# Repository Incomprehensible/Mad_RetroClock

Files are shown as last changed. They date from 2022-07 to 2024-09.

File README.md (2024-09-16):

# Retro style desk clock

Powered via 5V USB-C interface. Provides a 2S Li-Ion battery pack for autonomous operation.\
Made with 4 IN-12A Nixie Tubes denoting hours & minutes, and smaller INS-1 tubes as the dots.\
Enabled with Wi-Fi connectivity for automatic time synchronization using the Network Time Protocol (NTP).\
Functions as a simple clock and an alarm clock. User interface for the alarm setting is implemented with 2 Set/Unset buttons and rotary encoder.\
There's an MP3-player onboard any melody can be programmed and set as an alarm call.





## Gallery
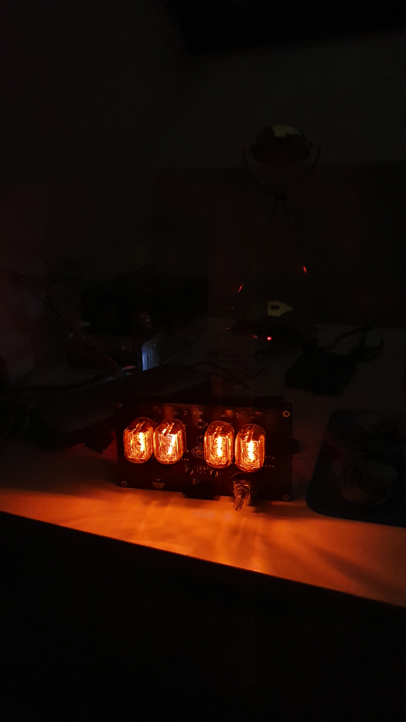
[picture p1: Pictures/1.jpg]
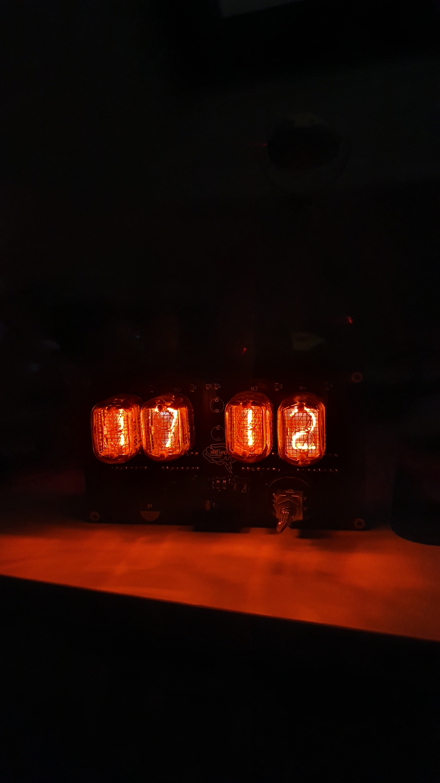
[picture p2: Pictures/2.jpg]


<details><summary>More photos</summary>
<p>

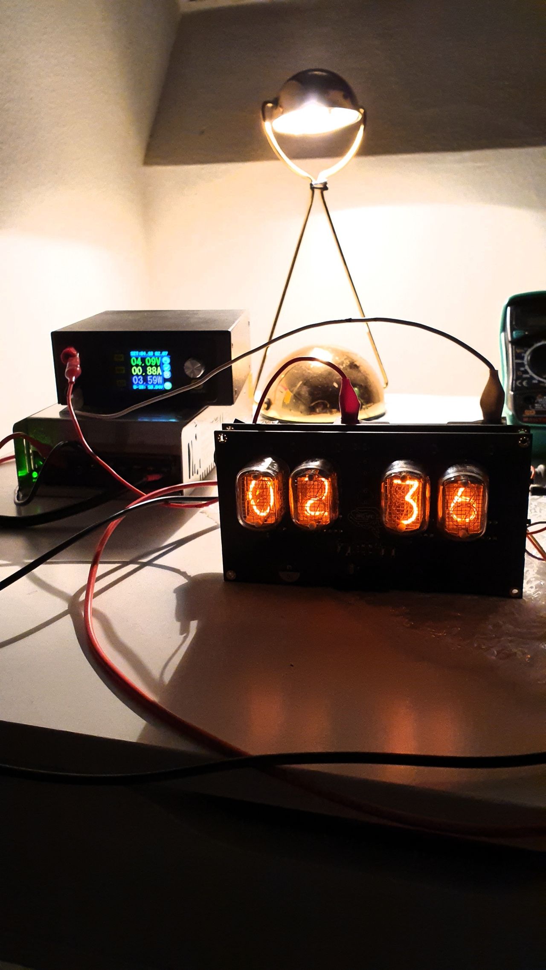
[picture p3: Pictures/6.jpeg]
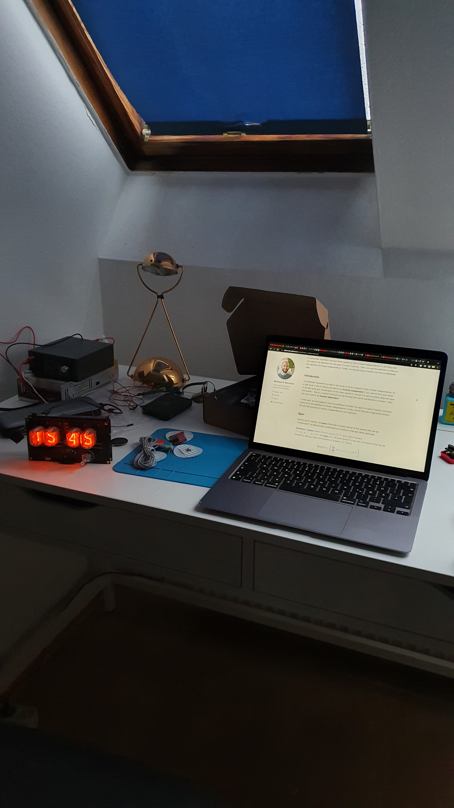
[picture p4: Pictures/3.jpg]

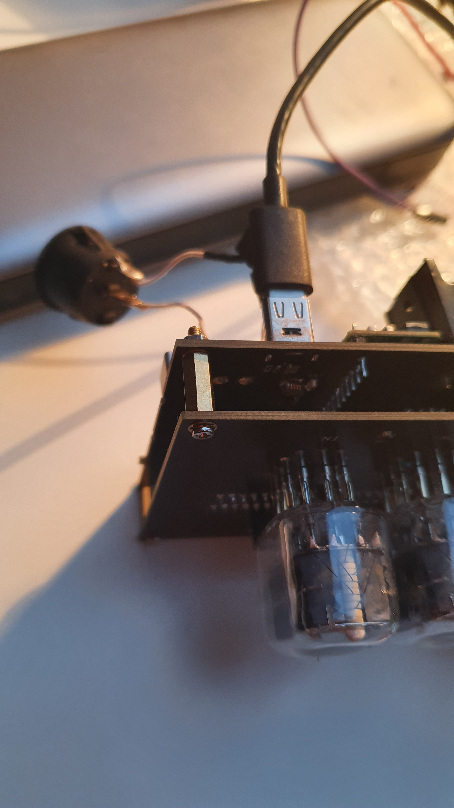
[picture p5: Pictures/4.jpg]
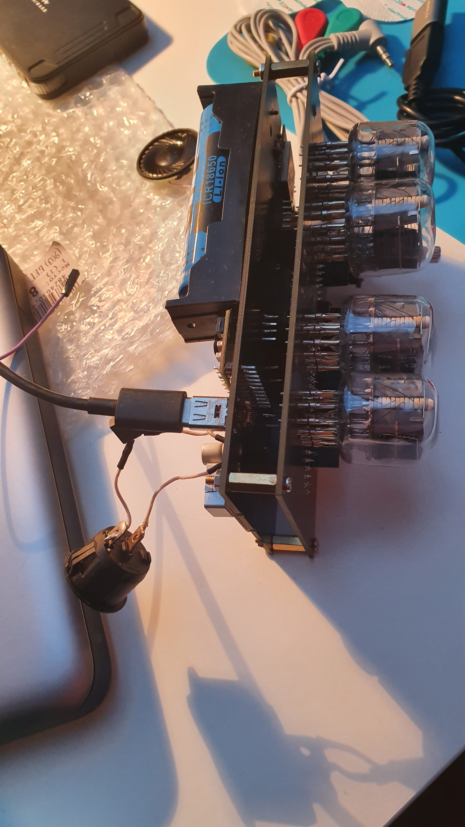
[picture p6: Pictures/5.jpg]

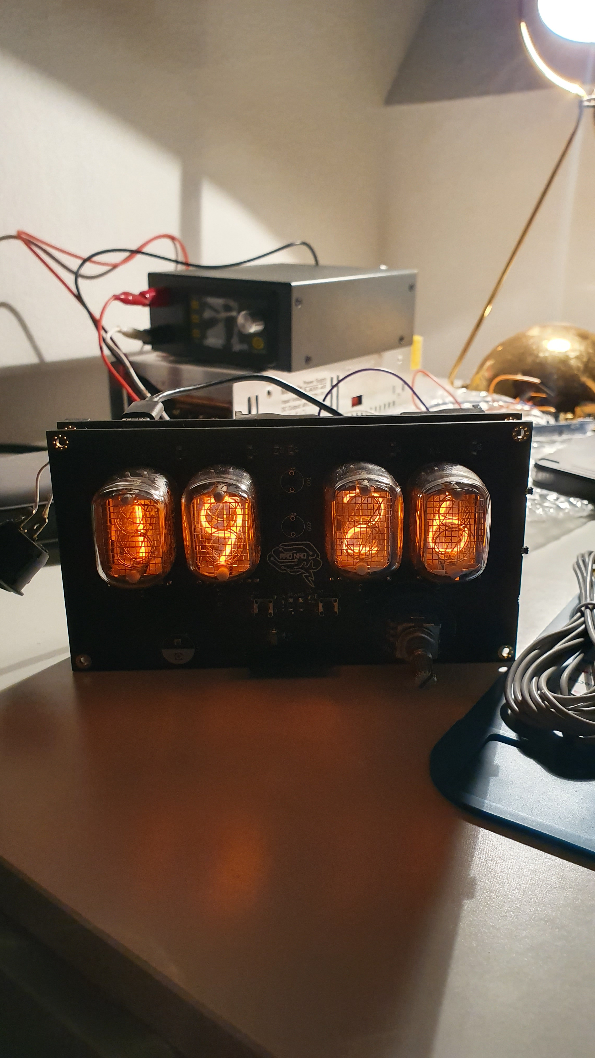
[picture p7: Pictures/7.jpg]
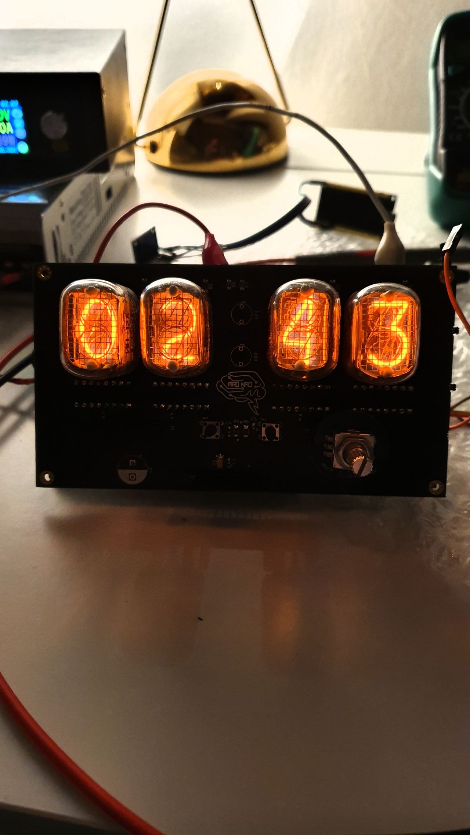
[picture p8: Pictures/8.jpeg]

</p>
</details>

## Further steps
* Enclosure design
* Add remote app control / IOT host node connectivity
* Better power design to get rid of inrush current issue preventing the device to start up sometimes without USB power attached

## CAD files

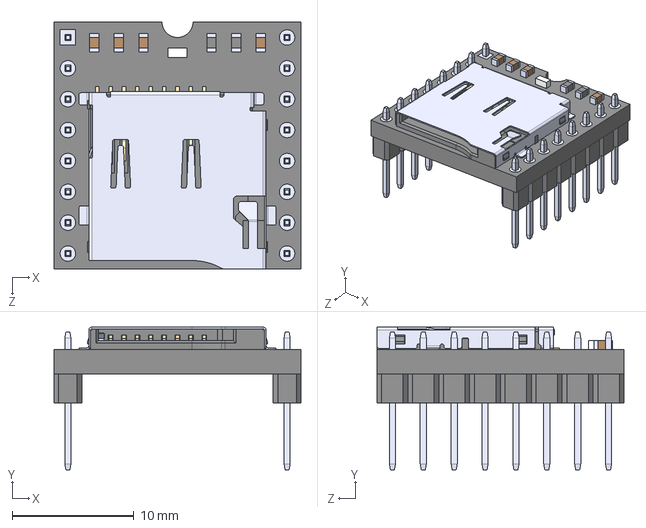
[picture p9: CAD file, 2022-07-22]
3D/DFR0299.step
20.3 x 11.8 x 20.3 mm

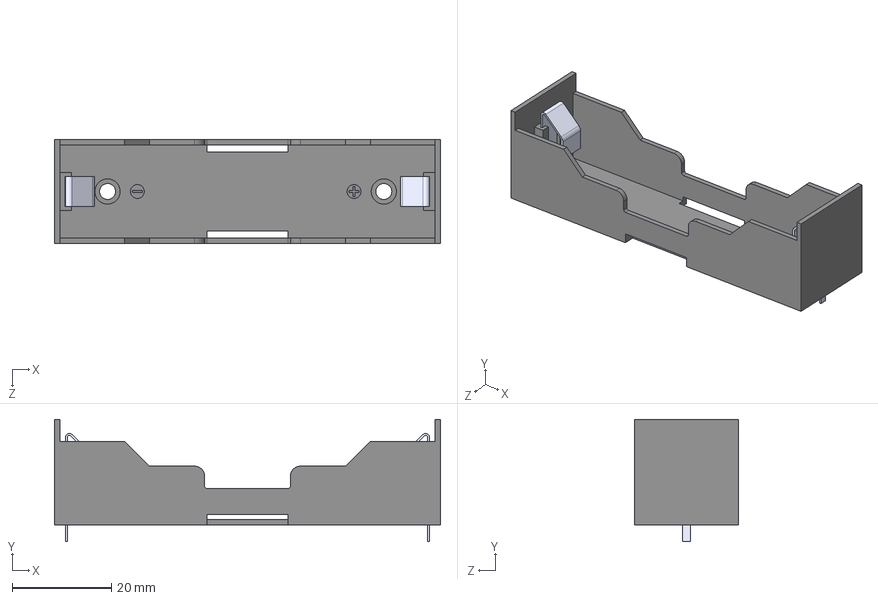
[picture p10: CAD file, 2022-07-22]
3D/BH-18650-PC.step
77.7 x 24.6 x 20.9 mm

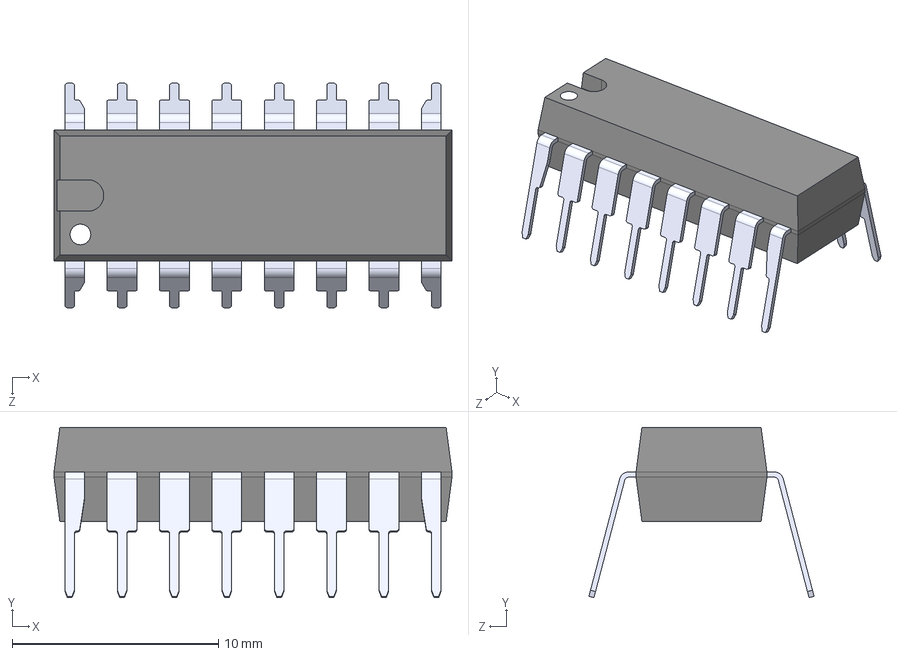
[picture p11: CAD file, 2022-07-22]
3D/SN74HC595N.step
19.3 x 8.25 x 10.9 mm

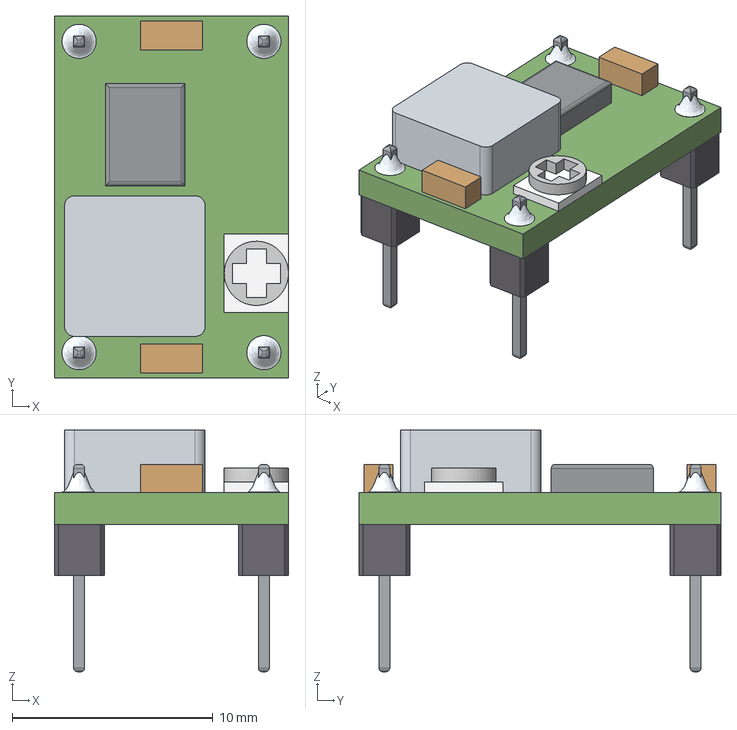
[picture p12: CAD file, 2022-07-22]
3D/dsn-mini-360.step
11.7 x 18.0 x 12.0 mm

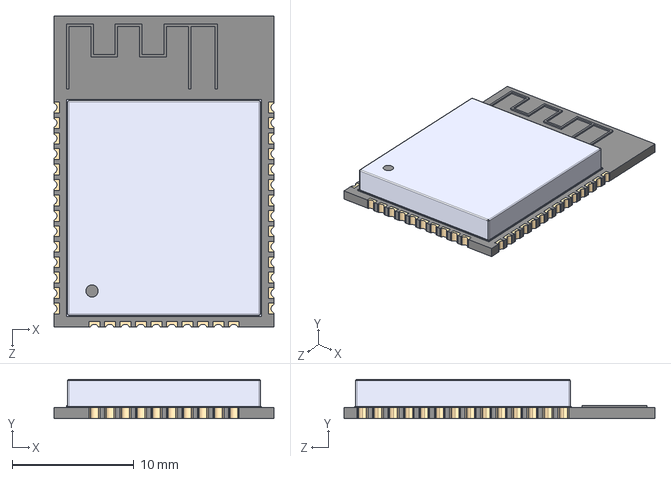
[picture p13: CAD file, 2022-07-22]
3D/ESP32-WROOM-32.step
18.0 x 3.20 x 25.5 mm

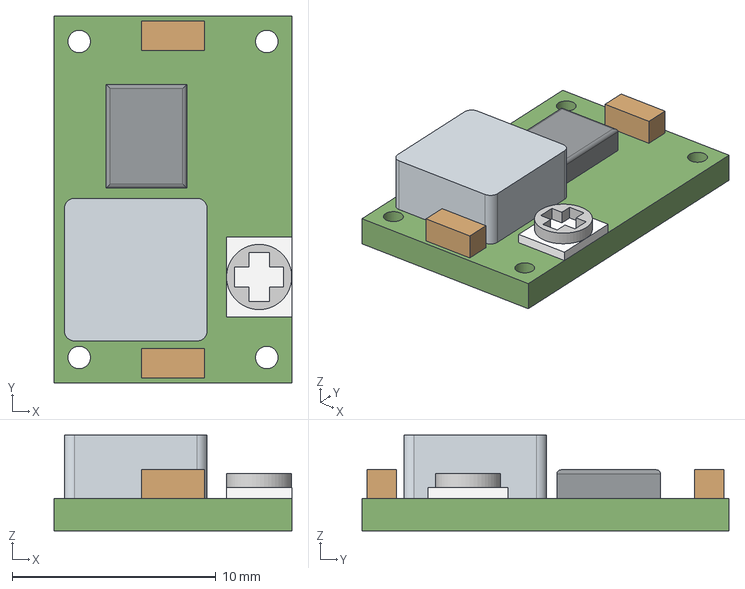
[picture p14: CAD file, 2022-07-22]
3D/dsn-mini-360-no-pins.step
11.7 x 18.0 x 4.70 mm

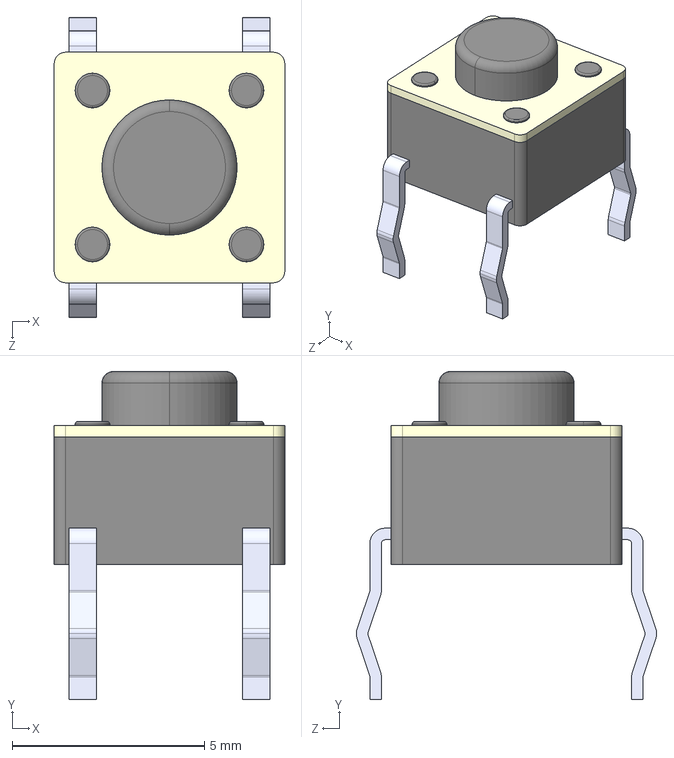
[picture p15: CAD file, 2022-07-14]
3D/KLS7-TS6601-13.0-180.step
5.99 x 8.52 x 7.80 mm

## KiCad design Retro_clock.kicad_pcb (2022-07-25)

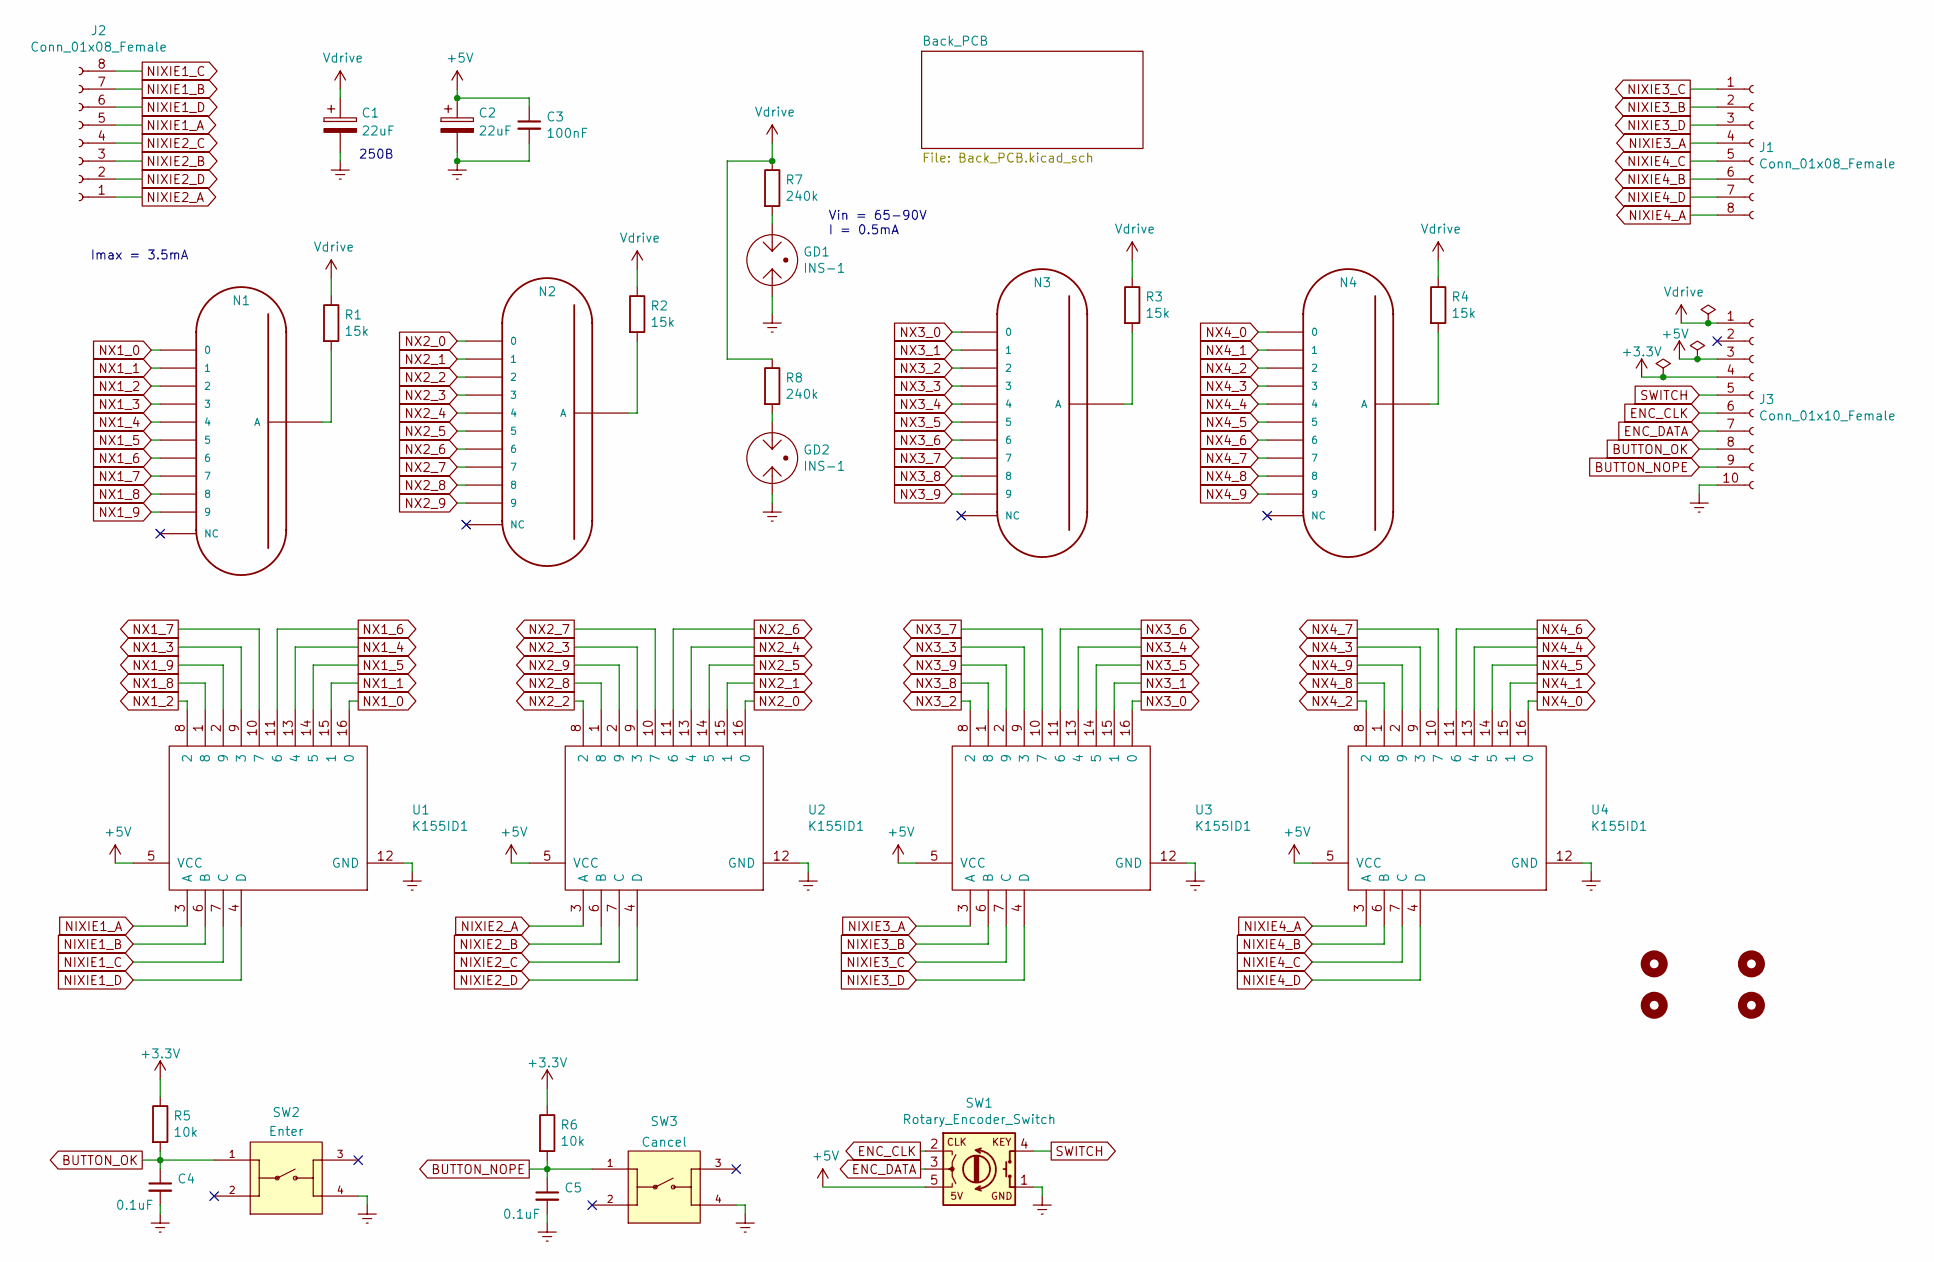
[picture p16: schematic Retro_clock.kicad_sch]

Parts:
C1: 22uF; CP_Radial_D10.0mm_P5.00mm
C2: 22uF; CP_EIA-3216-10_Kemet-I_Pad1.58x1.35mm_HandSolder
C3: 100nF; C_0603_1608Metric_Pad1.08x0.95mm_HandSolder
C4, C5: 0.1uF; C_0603_1608Metric_Pad1.08x0.95mm_HandSolder
GD1, GD2: INS-1
H1, H2, H3, H4: MountingHole; MountingHole_2.5mm_Pad_Via
J1, J2: Conn_01x08_Female; PinSocket_1x08_P2.54mm_Vertical
J3: Conn_01x10_Female; PinSocket_1x10_P2.54mm_Vertical
N1, N2, N3, N4: IN-12A
R1, R2, R3, R4: 15k; R_1206_3216Metric_Pad1.30x1.75mm_HandSolder
R5, R6: 10k; R_1206_3216Metric_Pad1.30x1.75mm_HandSolder
R7, R8: 240k; R_0805_2012Metric_Pad1.20x1.40mm_HandSolder
SW1: Rotary_Encoder_Switch; Encoder
SW2: Enter; KLS7-TS6601-13.0-180
SW3: Cancel; KLS7-TS6601-13.0-180
U1, U2, U3, U4: K155ID1; DIP-16_W7.62mm

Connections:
+3.3V: J3.4, R5.1, R6.1
+5V: C2.1, C3.1, J3.3, SW1.5 (5V), U1.5 (VCC), U2.5 (VCC), U3.5 (VCC), U4.5 (VCC)
BUTTON_NOPE: C5.1, J3.9, R6.2, SW3.1
BUTTON_OK: C4.1, J3.8, R5.2, SW2.1
ENC_CLK: J3.6, SW1.2 (CLK)
ENC_DATA: J3.7, SW1.3 (DATA)
Earth: C1.2, C2.2, C3.2, C4.2, C5.2, GD1.2, GD2.2, J3.10, SW1.1 (GND), SW2.4, SW3.4, U1.12 (GND), U2.12 (GND), U3.12 (GND), U4.12 (GND)
NIXIE1_A: J2.5, U1.3 (A)
NIXIE1_B: J2.7, U1.6 (B)
NIXIE1_C: J2.8, U1.7 (C)
NIXIE1_D: J2.6, U1.4 (D)
NIXIE2_A: J2.1, U2.3 (A)
NIXIE2_B: J2.3, U2.6 (B)
NIXIE2_C: J2.4, U2.7 (C)
NIXIE2_D: J2.2, U2.4 (D)
NIXIE3_A: J1.4, U3.3 (A)
NIXIE3_B: J1.2, U3.6 (B)
NIXIE3_C: J1.1, U3.7 (C)
NIXIE3_D: J1.3, U3.4 (D)
NIXIE4_A: J1.8, U4.3 (A)
NIXIE4_B: J1.6, U4.6 (B)
NIXIE4_C: J1.5, U4.7 (C)
NIXIE4_D: J1.7, U4.4 (D)
NX1_0: N1.2 (0), U1.16 (0)
NX1_1: N1.11 (1), U1.15 (1)
NX1_2: N1.10 (2), U1.8 (2)
NX1_3: N1.9 (3), U1.9 (3)
NX1_4: N1.8 (4), U1.13 (4)
NX1_5: N1.7 (5), U1.14 (5)
NX1_6: N1.6, U1.11 (6)
NX1_7: N1.5 (7), U1.10 (7)
NX1_8: N1.4 (8), U1.1 (8)
NX1_9: N1.3 (9), U1.2 (9)
NX2_0: N2.2 (0), U2.16 (0)
NX2_1: N2.11 (1), U2.15 (1)
NX2_2: N2.10 (2), U2.8 (2)
NX2_3: N2.9 (3), U2.9 (3)
NX2_4: N2.8 (4), U2.13 (4)
NX2_5: N2.7 (5), U2.14 (5)
NX2_6: N2.6, U2.11 (6)
NX2_7: N2.5 (7), U2.10 (7)
NX2_8: N2.4 (8), U2.1 (8)
NX2_9: N2.3 (9), U2.2 (9)
NX3_0: N3.2 (0), U3.16 (0)
NX3_1: N3.11 (1), U3.15 (1)
NX3_2: N3.10 (2), U3.8 (2)
NX3_3: N3.9 (3), U3.9 (3)
NX3_4: N3.8 (4), U3.13 (4)
NX3_5: N3.7 (5), U3.14 (5)
NX3_6: N3.6, U3.11 (6)
NX3_7: N3.5 (7), U3.10 (7)
NX3_8: N3.4 (8), U3.1 (8)
NX3_9: N3.3 (9), U3.2 (9)
NX4_0: N4.2 (0), U4.16 (0)
NX4_1: N4.11 (1), U4.15 (1)
NX4_2: N4.10 (2), U4.8 (2)
NX4_3: N4.9 (3), U4.9 (3)
NX4_4: N4.8 (4), U4.13 (4)
NX4_5: N4.7 (5), U4.14 (5)
NX4_6: N4.6, U4.11 (6)
NX4_7: N4.5 (7), U4.10 (7)
NX4_8: N4.4 (8), U4.1 (8)
NX4_9: N4.3 (9), U4.2 (9)
unnamed: GD1.1, R7.2
unnamed: GD2.1, R8.2
unnamed: N1.1 (A), R1.2
unnamed: N2.1 (A), R2.2
unnamed: N3.1 (A), R3.2
unnamed: N4.1 (A), R4.2
SWITCH: J3.5, SW1.4 (KEY)
Vdrive: C1.1, J3.1, R1.1, R2.1, R3.1, R4.1, R7.1, R8.1

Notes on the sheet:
Imax = 3.5mA
Vin = 65-90V I = 0.5mA
250В

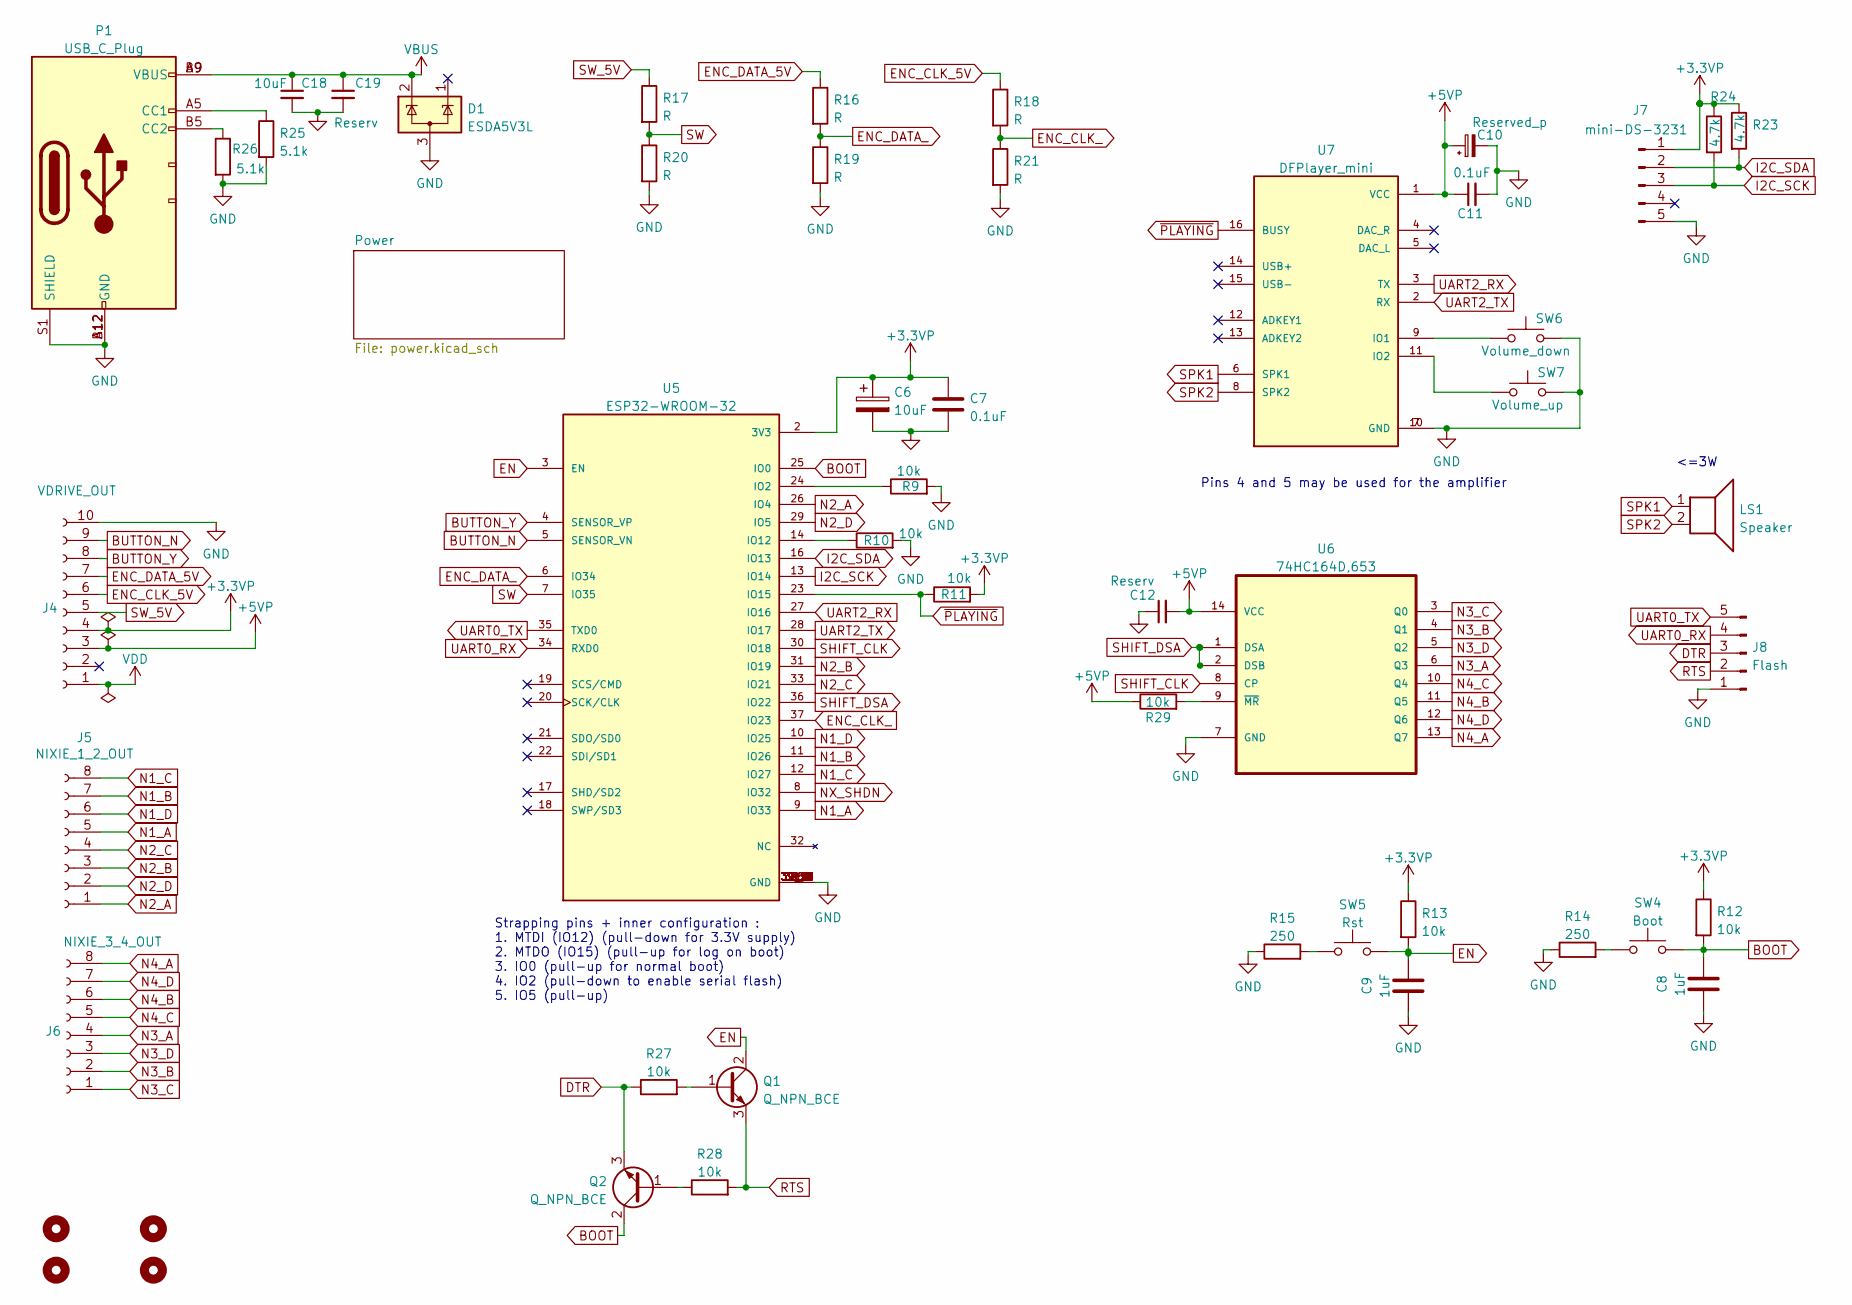
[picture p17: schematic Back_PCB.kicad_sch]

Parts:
C6, C18: 10uF; C_0603_1608Metric_Pad1.08x0.95mm_HandSolder
C7, C11: 0.1uF; C_0603_1608Metric_Pad1.08x0.95mm_HandSolder
C8, C9: 1uF; C_0603_1608Metric_Pad1.08x0.95mm_HandSolder
C10: Reserved_p; C_0603_1608Metric_Pad1.08x0.95mm_HandSolder
C12, C19: Reserv; C_0603_1608Metric_Pad1.08x0.95mm_HandSolder
D1: ESDA5V3L; SOT-23
H5, H6, H7, H8: MountingHole; MountingHole_2.5mm_Pad_Via
J4: VDRIVE_OUT; PinSocket_1x10_P2.54mm_Vertical
J5: NIXIE_1_2_OUT; PinSocket_1x08_P2.54mm_Vertical
J6: NIXIE_3_4_OUT; PinSocket_1x08_P2.54mm_Vertical
J7: mini-DS-3231; DS3231-Mini
J8: Flash; PinHeader_1x05_P2.54mm_Vertical
LS1: Speaker; Speaker_conn
P1: USB_C_Plug; usb_c_receptable_hro_type-c-31-m-17
Q1, Q2: Q_NPN_BCE; SOT-23_Handsoldering
R9, R10, R11, R12, R13, R27, R28, R29: 10k; R_0603_1608Metric_Pad0.98x0.95mm_HandSolder
R14, R15: 250; R_0603_1608Metric_Pad0.98x0.95mm_HandSolder
R16, R17, R18, R19, R20, R21: R; R_0603_1608Metric_Pad0.98x0.95mm_HandSolder
R23, R24: 4.7k; R_0603_1608Metric_Pad0.98x0.95mm_HandSolder
R25, R26: 5.1k; R_0603_1608Metric_Pad0.98x0.95mm_HandSolder
SW4: Boot; SW_TS-1187A-B-A-B
SW5: Rst; SW_TS-1187A-B-A-B
SW6: Volume_down; KLS7-TS6601-13.0-180
SW7: Volume_up; KLS7-TS6601-13.0-180
U5: ESP32-WROOM-32; MODULE_ESP32-WROOM-32; PARTREV 2.9
U6: 74HC164D,653; SOIC127P600X175-14N; MPN 74HC164D,653
U7: DFPlayer_mini; MODULE_DFR0299

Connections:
+3.3VP: C6.1, C7.1, J4.4, J7.1, R11.2, R12.1, R13.1, R23.1, R24.1, U5.2 (3V3); also elsewhere on the board
+5VP: C10.1, C11.1, C12.2, J4.3, R29.1, U6.14 (VCC), U7.1 (VCC); also elsewhere on the board
BOOT: C8.2, Q2.2 (C), R12.2, SW4.2, U5.25 (IO0)
BUTTON_N: J4.9, U5.5 (SENSOR_VN)
BUTTON_Y: J4.8, U5.4 (SENSOR_VP)
DTR: J8.3, Q2.3 (E), R27.1
EN: C9.2, Q1.2 (C), R13.2, SW5.2, U5.3 (EN)
ENC_CLK_: R18.2, R21.1, U5.37 (IO23)
ENC_CLK_5V: J4.6, R18.1
ENC_DATA_: R16.2, R19.1, U5.6 (IO34)
ENC_DATA_5V: J4.7, R16.1
GND: C6.2, C7.2, C8.1, C9.1, C10.2, C11.2, C12.1, C18.2, C19.2, D1.3 (A), J4.10, J7.5, J8.1, P1.A12 (GND), P1.B12 (GND), P1.S1 (SHIELD), R9.2, R10.2, R14.1, R15.1, R19.2, R20.2, R21.2, R25.2, R26.2, SW6.2, SW7.2, U5.1 (GND), U5.15 (GND), U5.38 (GND), U5.39_1 (GND), U5.39_2 (GND), U5.39_3 (GND), U5.39_4 (GND), U5.39_5 (GND), U5.39_6 (GND), U5.39_7 (GND), U5.39_8 (GND), U5.39_9 (GND), U5.39_10 (GND), U5.39_11 (GND), U5.39_12 (GND), U5.39_13 (GND), U5.39_14 (GND), U5.39_15 (GND), U5.39_16 (GND), U5.39_17 (GND), U5.39_18 (GND), U5.39_19 (GND), U5.39_20 (GND), U5.39_21 (GND), U6.7 (GND), U7.7 (GND), U7.10 (GND); also elsewhere on the board
I2C_SCK: J7.3, R24.2, U5.13 (IO14)
I2C_SDA: J7.2, R23.2, U5.16 (IO13)
N1_A: J5.5, U5.9 (IO33)
N1_B: J5.7, U5.11 (IO26)
N1_C: J5.8, U5.12 (IO27)
N1_D: J5.6, U5.10 (IO25)
N2_A: J5.1, U5.26 (IO4)
N2_B: J5.3, U5.31 (IO19)
N2_C: J5.4, U5.33 (IO21)
N2_D: J5.2, U5.29 (IO5)
N3_A: J6.4, U6.6 (Q3)
N3_B: J6.2, U6.4 (Q1)
N3_C: J6.1, U6.3 (Q0)
N3_D: J6.3, U6.5 (Q2)
N4_A: J6.8, U6.13 (Q7)
N4_B: J6.6, U6.11 (Q5)
N4_C: J6.5, U6.10 (Q4)
N4_D: J6.7, U6.12 (Q6)
NX_SHDN: U5.8 (IO32); also elsewhere on the board
unnamed: P1.A5 (CC1), R25.1
unnamed: P1.B5 (CC2), R26.1
unnamed: Q1.1 (B), R27.2
unnamed: Q2.1 (B), R28.1
unnamed: R9.1, U5.24 (IO2)
unnamed: R10.1, U5.14 (IO12)
unnamed: R14.2, SW4.1
unnamed: R15.2, SW5.1
unnamed: R29.2, U6.9 (~MR)
unnamed: SW6.1, U7.9 (IO1)
unnamed: SW7.1, U7.11 (IO2)
RTS: J8.2, Q1.3 (E), R28.2
SHIFT_CLK: U5.30 (IO18), U6.8 (CP)
SHIFT_DSA: U5.36 (IO22), U6.1 (DSA)
SPK1: LS1.1, U7.6 (SPK1)
SPK2: LS1.2, U7.8 (SPK2)
SW: R17.2, R20.1, U5.7 (IO35)
SW_5V: J4.5, R17.1
UART0_RX: J8.4, U5.34 (RXD0)
UART0_TX: J8.5, U5.35 (TXD0)
UART2_RX: U5.27 (IO16), U7.3 (TX)
UART2_TX: U5.28 (IO17), U7.2 (RX)
VBUS: C18.1, C19.1, D1.2 (K), P1.A9 (VBUS), P1.B9 (VBUS); also elsewhere on the board
VDD: J4.1; also elsewhere on the board
~PLAYING: R11.1, U5.23 (IO15), U7.16 (BUSY)

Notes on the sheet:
<=3W
Pins 4 and 5 may be used for the amplifier
Strapping pins + inner configuration : 1. MTDI (IO12) (pull-down for 3.3V supply) 2. MTDO (IO15) (pull-up for log on boot) 3. IO0 (pull-up for normal boot) 4. IO2 (pull-down to enable serial flash) 5. IO5 (pull-up)

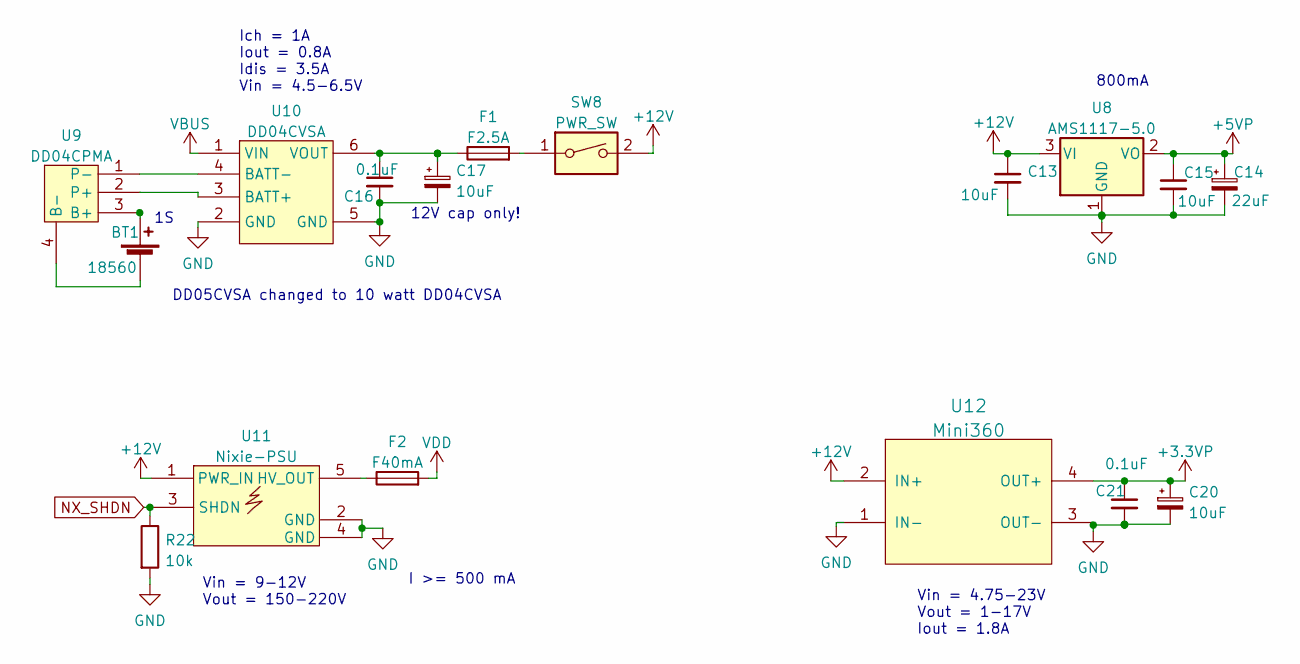
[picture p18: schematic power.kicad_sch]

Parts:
BT1: 18560; BAT_BH-18650-PC
C13, C15, C20: 10uF; C_0603_1608Metric_Pad1.08x0.95mm_HandSolder
C14: 22uF; CP_EIA-3216-10_Kemet-I_Pad1.58x1.35mm_HandSolder
C16, C21: 0.1uF; C_0603_1608Metric_Pad1.08x0.95mm_HandSolder
C17: 10uF; C_0805_2012Metric_Pad1.18x1.45mm_HandSolder
F1: F2.5A; Fuse_1206_3216Metric_Pad1.42x1.75mm_HandSolder
F2: F40mA; Fuse_1206_3216Metric_Pad1.42x1.75mm_HandSolder
R22: 10k; R_0603_1608Metric_Pad0.98x0.95mm_HandSolder
SW8: PWR_SW; PWR_SWITCH
U8: AMS1117-5.0; SOT-223-3_TabPin2
U9: DD04CPMA
U10: DD04CVSA
U11: Nixie-PSU
U12: Mini360; Mini360_step-down

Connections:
+3.3VP: C20.1, C21.1, U12.4 (OUT+); also elsewhere on the board
+5VP: C14.1, C15.1, U8.2 (VO); also elsewhere on the board
+12V: C13.1, SW8.2, U8.3 (VI), U11.1 (PWR_IN), U12.2 (IN+)
GND: C13.2, C14.2, C15.2, C16.2, C17.2, C20.2, C21.2, R22.2, U8.1 (GND), U10.2 (GND), U10.5 (GND), U11.2 (GND), U11.4 (GND), U12.1 (IN-), U12.3 (OUT-); also elsewhere on the board
NX_SHDN: R22.1, U11.3 (SHDN); also elsewhere on the board
unnamed: BT1.1 (+), U9.3 (B+)
unnamed: BT1.2 (-), U9.4 (B-)
unnamed: C16.1, C17.1, F1.1, U10.6 (VOUT)
unnamed: F1.2, SW8.1
unnamed: F2.1, U11.5 (HV_OUT)
unnamed: U9.2 (P+), U10.3 (BATT+)
unnamed: U9.1 (P-), U10.4 (BATT-)
VBUS: U10.1 (VIN); also elsewhere on the board
VDD: F2.2; also elsewhere on the board

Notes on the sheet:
Vin = 9-12V Vout = 150-220V
800mA
DD05CVSA changed to 10 watt DD04CVSA
12V cap only!
Vin = 4.75-23V Vout = 1-17V Iout = 1.8A
Ich = 1A Iout = 0.8A Idis = 3.5A Vin = 4.5-6.5V
I >= 500 mA

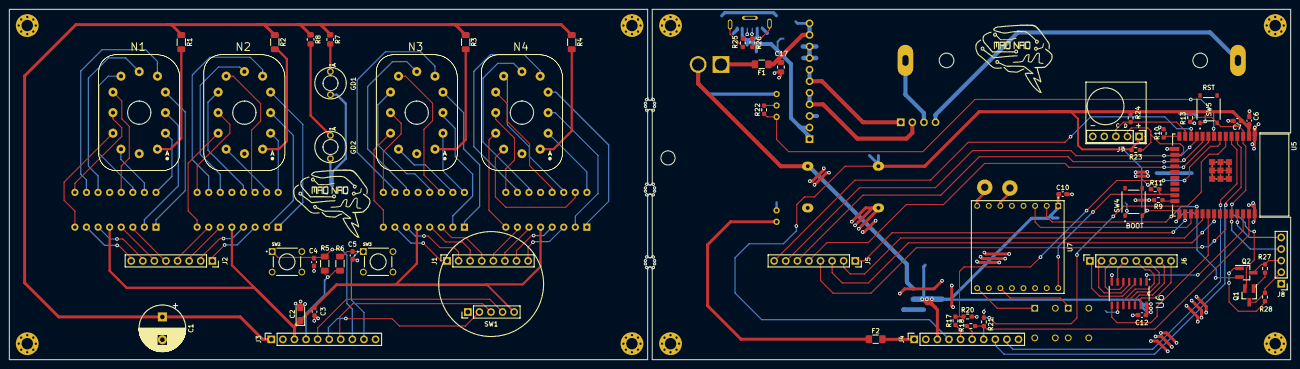
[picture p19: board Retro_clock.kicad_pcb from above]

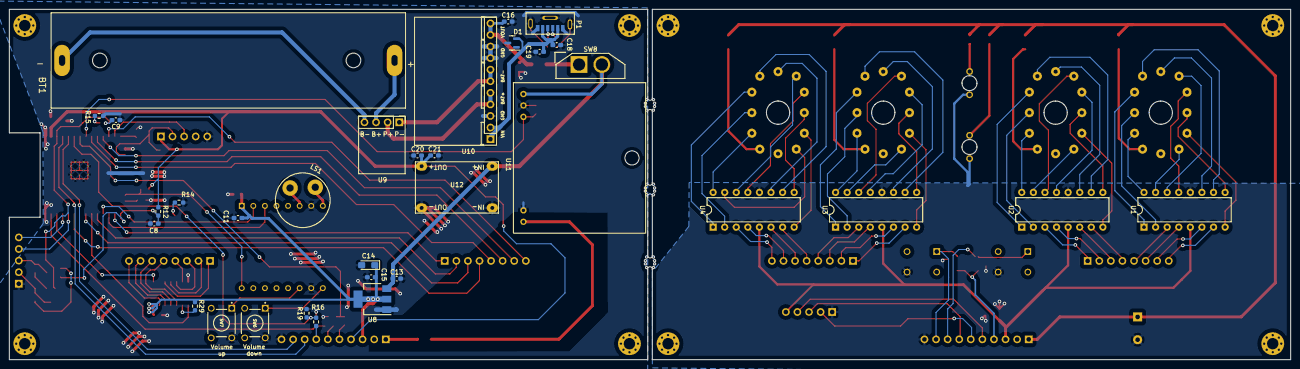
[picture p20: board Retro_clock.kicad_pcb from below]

Board: 2 copper layers, 280.9 x 76.8 mm, 103 parts (33 on the bottom side), 135 nets.

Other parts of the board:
mouse-bite-1mm-slot, mouse-bite-1mm-slot#2, mouse-bite-1mm-slot#3: VAL**; mouse-bite-1mm-slot

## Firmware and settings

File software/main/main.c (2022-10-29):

/* Hello World Example

   This example code is in the Public Domain (or CC0 licensed, at your option.)

   Unless required by applicable law or agreed to in writing, this
   software is distributed on an "AS IS" BASIS, WITHOUT WARRANTIES OR
   CONDITIONS OF ANY KIND, either express or implied.
*/
#include <stdio.h>
#include <string.h>
#include "sdkconfig.h"
#include "freertos/FreeRTOS.h"
#include "freertos/task.h"
#include "freertos/queue.h"
#include "esp_system.h"
#include "nvs_flash.h"
#include "esp_spi_flash.h"
#include "pins.h"
#include "shift_register.h"
#include "driver/i2c.h"
#include "esp_log.h"
#include "../RTC/ds3231.h"
#include "shift_register.h"
#include "esp_sleep.h"
#include "dfplayer.h"
#include "debug.h"
#include "test_hardware.h"

QueueHandle_t uart_queue;

struct Alarm {
    struct tm time;
    bool set;
};

struct encoder_data {
    int clk;
    int data;
} __attribute__((PACKED));

static const char *I2C = "I2C";

volatile bool ALARM_MODE_SET = false;
volatile bool NEXT_NIXIE = false;
volatile bool ALARM_SET = false;
volatile bool ALARM_UNSET = false;
volatile bool TURN_RIGHT = false;
volatile bool TURN_LEFT = false;
volatile bool BLOCK_LEFT = false;
volatile bool BLOCK_RIGHT = false;

bool obtain_time(struct tm*);

QueueHandle_t handle = NULL;

static void IRAM_ATTR switch_isr_handler(void* arg)
{
    if (ALARM_MODE_SET)
        NEXT_NIXIE = true;
    else
        ALARM_MODE_SET = true;
}

static void IRAM_ATTR encoder_isr_handler(void* arg)
{
    struct encoder_data data = {
        .clk = gpio_get_level(ENC_CLK_PIN),
        .data = gpio_get_level(ENC_DATA_PIN),
    };
    BaseType_t ContextSwitchRequest = pdFALSE;
 
    xQueueSendToBackFromISR(handle,(void*)&data,&ContextSwitchRequest);
   
    if(ContextSwitchRequest){
        taskYIELD();
    }
}

static void IRAM_ATTR button_isr_handler(void* arg)
{
    if ((uint32_t)arg == BUTTON_Y_PIN) {
        ALARM_SET = true;
        ALARM_UNSET = false;
    }
    else {
        ALARM_SET = false;
        ALARM_UNSET = true;
    }
}

void init_gpio()
{
    gpio_set_direction(SHDN_PIN, GPIO_MODE_OUTPUT);
    gpio_set_direction(N1A_PIN, GPIO_MODE_OUTPUT);
    gpio_set_direction(N1B_PIN, GPIO_MODE_OUTPUT);
    gpio_set_direction(N1C_PIN, GPIO_MODE_OUTPUT);
    gpio_set_direction(N1D_PIN, GPIO_MODE_OUTPUT);
    gpio_set_direction(N2A_PIN, GPIO_MODE_OUTPUT);
    gpio_set_direction(N2B_PIN, GPIO_MODE_OUTPUT);
    gpio_set_direction(N2C_PIN, GPIO_MODE_OUTPUT);
    gpio_set_direction(N2D_PIN, GPIO_MODE_OUTPUT);
    gpio_set_direction(SHIFT_CLK_PIN, GPIO_MODE_OUTPUT);
    gpio_set_direction(SHIFT_DSA_PIN, GPIO_MODE_OUTPUT);

    gpio_set_direction(SWITCH_PIN, GPIO_MODE_INPUT);
    gpio_set_direction(ENC_DATA_PIN, GPIO_MODE_INPUT);
    gpio_set_direction(ENC_CLK_PIN, GPIO_MODE_INPUT);
    gpio_set_direction(BUTTON_Y_PIN, GPIO_MODE_INPUT);
    gpio_set_direction(BUTTON_N_PIN, GPIO_MODE_INPUT);

    gpio_set_level(SHDN_PIN, 1);

    gpio_set_level(N1A_PIN, 0);
    gpio_set_level(N1B_PIN, 0);
    gpio_set_level(N1C_PIN, 0);
    gpio_set_level(N1D_PIN, 0);
    gpio_set_level(N2A_PIN, 0);
    gpio_set_level(N2B_PIN, 0);
    gpio_set_level(N2C_PIN, 0);
    gpio_set_level(N2D_PIN, 0);
    
    gpio_set_level(SHIFT_DSA_PIN, 0);
    gpio_set_level(SHIFT_CLK_PIN, 0);

    if (gpio_install_isr_service(0) != ESP_OK)
        ESP_LOGE("GPIO", "Error in gpio_install_isr_service()");
    gpio_set_intr_type(SWITCH_PIN, GPIO_INTR_NEGEDGE);
    if (gpio_isr_handler_add(SWITCH_PIN, switch_isr_handler, NULL) != ESP_OK)
        ESP_LOGE("GPIO", "Error in gpio_isr_handler_add() for switch");
    if (gpio_intr_enable(SWITCH_PIN) != ESP_OK)
        ESP_LOGE("GPIO", "Error in gpio_intr_enable() for switch");

    gpio_set_intr_type(ENC_CLK_PIN, GPIO_INTR_ANYEDGE);
    if (gpio_isr_handler_add(ENC_CLK_PIN, encoder_isr_handler, (void*) ENC_CLK_PIN) != ESP_OK)
        ESP_LOGE("GPIO", "Error in gpio_isr_handler_add() for enc_clk");
    
    gpio_set_intr_type(BUTTON_Y_PIN, GPIO_INTR_NEGEDGE);
    if (gpio_isr_handler_add(BUTTON_Y_PIN, button_isr_handler, (void*) BUTTON_Y_PIN) != ESP_OK)
        ESP_LOGE("GPIO", "Error in gpio_isr_handler_add() for button_y");
    gpio_set_intr_type(BUTTON_N_PIN, GPIO_INTR_NEGEDGE);
    gpio_isr_handler_add(BUTTON_N_PIN, button_isr_handler, (void*) BUTTON_N_PIN);
    gpio_intr_disable(ENC_DATA_PIN);
    gpio_intr_disable(ENC_CLK_PIN);
    gpio_intr_disable(BUTTON_Y_PIN);
    gpio_intr_disable(BUTTON_N_PIN);
}

void power_nixie(bool on)
{
    if (on)
        gpio_set_level(SHDN_PIN, 0);
    else
        gpio_set_level(SHDN_PIN, 1);
}

esp_err_t uart_init()
{
    const uart_port_t uart_num = UART_NUM;
    esp_err_t err;
    uart_config_t uart_config = {
        .baud_rate = BAUD_RATE,
        .data_bits = UART_DATA_8_BITS,
        .parity = UART_PARITY_DISABLE,
        .stop_bits = UART_STOP_BITS_1,
        .flow_ctrl = UART_HW_FLOWCTRL_DISABLE,
        // .rx_flow_ctrl_thresh = 122,
    };

    // Install UART driver using an event queue here
    ESP_ERROR_CHECK(uart_driver_install(uart_num, UART_BUFF_SIZE, \
                                        UART_BUFF_SIZE, UART_QUEUE_SIZE, &uart_queue, 0));
    err = uart_param_config(uart_num, &uart_config);
    if (err != ESP_OK)
        return err;
    
    err = uart_set_pin(uart_num, UART_TX_PIN, UART_RX_PIN, UART_PIN_NO_CHANGE, UART_PIN_NO_CHANGE);
    if (err != ESP_OK)
        return err;
 
    err = uart_set_mode(uart_num, UART_MODE_UART);
    if (err != ESP_OK)
        return err;
    
    esp_log_level_set("UART", ESP_LOG_INFO);
    return ESP_OK;
}

esp_err_t i2c_master_init(i2c_dev_t *dev, i2c_port_t port)
{
    i2c_config_t conf = {
        .mode = I2C_MODE_MASTER,
        .sda_pullup_en = GPIO_PULLUP_DISABLE,
        .scl_pullup_en = GPIO_PULLUP_DISABLE,
        .master.clk_speed = dev->clk_speed,
        .sda_io_num = dev->sda_io_num,
        .scl_io_num = dev->scl_io_num,
        .clk_flags = 0,
    };

    i2c_param_config(port, &conf);
    return i2c_driver_install(port, conf.mode, 0, 0, 0);
}

void init_RTC(i2c_dev_t *dev, struct tm *time, bool set_time)
{
    if (i2c_master_init(dev, I2C_NUM_0) != ESP_OK) {
        ESP_LOGE(I2C, "I2C init failed.\n");
        return;
    }

    if (set_time && ds3231_set_time(dev, time) != ESP_OK) {
        ESP_LOGE(I2C, "Couldn't set time in mini RTS module.\n");
        return;
    }
    
    if (ds3231_get_time(dev, time) != ESP_OK) {
        ESP_LOGE(I2C, "Couldn't ask the current time.\n");
        return;
    }
    ESP_LOGI(I2C, "Current time: %d : %d : %d", time->tm_hour, time->tm_min , time->tm_sec);
}

void init_DFPlayer()
{
    execute_command(DFP_REQ_PARAMS, 0x0);
    await_feedback();
    // vTaskDelay(300 / portTICK_PERIOD_MS);
    execute_command(DFP_PAUSE, 0);
    vTaskDelay(300 / portTICK_PERIOD_MS);
    execute_command(DFP_VOL, DEFAULT_VOLUME);
    vTaskDelay(300 / portTICK_PERIOD_MS);
    // execute_command(DFP_STANDBY, 0);
    execute_command(DFP_PLAY, DFP_PLAY_SLEEP);
}

void set_hour(uint8_t A, uint8_t B)
{
    gpio_set_level(N1A_PIN, A & 0x0001);
    gpio_set_level(N1B_PIN, (A >> 1) & 0x0001);
    gpio_set_level(N1C_PIN, (A >> 2) & 0x0001);
    gpio_set_level(N1D_PIN, (A >> 3) & 0x0001);
    gpio_set_level(N2A_PIN, B & 0x0001);
    gpio_set_level(N2B_PIN, (B >> 1) & 0x0001);
    gpio_set_level(N2C_PIN, (B >> 2) & 0x0001);
    gpio_set_level(N2D_PIN, (B >> 3) & 0x0001);
}

void set_time(int hour, int min)
{
    set_hour(hour / 10, hour % 10);
    set_minutes(min / 10, min % 10);
}

void set_number_by_nixie(uint8_t nixie, uint8_t* number)
{
    ESP_LOGI("ALARM", "set_number_by_nixie(): nixie: %d number: %d", nixie, *number);
    switch (nixie)
    {
        case (0):
        {
            gpio_set_level(N1A_PIN, *number & 0x0001);
            gpio_set_level(N1B_PIN, (*number >> 1) & 0x0001);
            gpio_set_level(N1C_PIN, (*number >> 2) & 0x0001);
            gpio_set_level(N1D_PIN, (*number >> 3) & 0x0001);
        } break;
        case (1):
        {
            gpio_set_level(N2A_PIN, *number & 0x0001);
            gpio_set_level(N2B_PIN, (*number >> 1) & 0x0001);
            gpio_set_level(N2C_PIN, (*number >> 2) & 0x0001);
            gpio_set_level(N2D_PIN, (*number >> 3) & 0x0001);
        } break;
        case (2): {
            set_minutes(*number, *(number+1));
        } break;
        case (3): {
            set_minutes(*(number-1), *number);
        } break;
        default:
            break;
    }
}

void get_rotation(struct encoder_data *data, uint8_t* num)
{
    if (data->clk == 0)
    {
        if (!BLOCK_LEFT && (data->data == 0))
        {
            BLOCK_LEFT = true;
            BLOCK_RIGHT = false;
        }
        else if (data->data == 1)
        {
            BLOCK_RIGHT = true;
            BLOCK_LEFT = false;
        }
    }
    else
    {
        if (BLOCK_LEFT && (data->data == 1))
        {
            *num = (*num == 0)? 9 : *num-1;
            BLOCK_LEFT = false;
        }
        else if (BLOCK_RIGHT && (data->data == 0))
        {
            *num = (*num + 1 > 9)? 0 : *num+1;
            BLOCK_RIGHT = false;
        }
    }
}

void run_alarm_mode(struct Alarm* timeinfo, QueueHandle_t* handle)
{
    uint8_t index = 0;
    uint8_t number[4] = { 0 };
    // enable all interrupts
    if (gpio_intr_enable(ENC_DATA_PIN) != ESP_OK)
        ESP_LOGE("GPIO", "Error in gpio_intr_enable() for enc_data");
    gpio_intr_enable(ENC_CLK_PIN);
    gpio_intr_enable(BUTTON_Y_PIN);
    gpio_intr_enable(BUTTON_N_PIN);

    set_time(timeinfo->time.tm_hour, timeinfo->time.tm_min);
    ESP_LOGI("ALARM", "hour: %d, min: %d", timeinfo->time.tm_hour, timeinfo->time.tm_min);
    number[0] = timeinfo->time.tm_hour / 10;
    number[1] = timeinfo->time.tm_hour % 10;
    number[2] = timeinfo->time.tm_min / 10;
    number[3] = timeinfo->time.tm_min % 10;

    struct encoder_data data = {0};
    while (!ALARM_SET && !ALARM_UNSET)
    {
        if (NEXT_NIXIE) {
                NEXT_NIXIE = false;
                index = (index + 1 > 3)? 0 : index + 1;
                ESP_LOGI("ALARM", "run_alarm_mode(): NEXT_NIXIE");
            }
        while (uxQueueMessagesWaiting(*handle))
        {
            if (NEXT_NIXIE) {
                NEXT_NIXIE = false;
                index = (index + 1 > 3)? 0 : index + 1;
                ESP_LOGI("ALARM", "run_alarm_mode(): NEXT_NIXIE");
            }
            xQueueReceive(*handle,(void*)&data,pdMS_TO_TICKS(100));
            get_rotation(&data, &number[index]);
            if (index == 0 && number[index] > 2)
                number[index] = 0;
            ESP_LOGI("ALARM", "run_alarm_mode(): index: %d number[]: %d", index, number[index]);
            set_number_by_nixie(index, &number[index]);
        }
        NEXT_NIXIE = false; // fix to prevent false triggers
        vTaskDelay(pdMS_TO_TICKS(100));
    }
    // unregister interrupts
    gpio_intr_disable(ENC_DATA_PIN);
    gpio_intr_disable(ENC_CLK_PIN);
    gpio_intr_disable(BUTTON_Y_PIN);
    ESP_LOGI("ALARM", "run_alarm_mode(): ALARM_SET or ALARM_UNSET");
    if (ALARM_SET)
    {
        ESP_LOGI("ALARM", "run_alarm_mode(): ALARM_SET");
        timeinfo->time.tm_hour = number[0]*10+number[1];
        timeinfo->time.tm_min = number[2]*10+number[3];
        timeinfo->set = true;
        ESP_LOGI("ALARM", "SET ALARM: 0: %d, 1: %d, 2: %d, 3: %d", number[0], number[1], number[2], number[3]);
        ESP_LOGI("ALARM", "SET ALARM: hour: %d, min: %d", number[0]*10+number[1], number[2]*10+number[3]);
    }
    if (!timeinfo->set)
     // we don't need to cancel any set alarms
        gpio_intr_disable(BUTTON_N_PIN);

    ALARM_MODE_SET = false;
    NEXT_NIXIE = false;
    ALARM_SET = false;
    ALARM_UNSET = false;
}

void annoying_alarm_mode(struct Alarm* alarm, struct tm* timeinfo, i2c_dev_t* dev)
{
    struct tm old_timeinfo = { 0 };

    gpio_intr_disable(SWITCH_PIN);
    gpio_intr_enable(BUTTON_Y_PIN);
    gpio_intr_enable(BUTTON_N_PIN);

    execute_command(DFP_TRACK, 3);

    while (!ALARM_SET && !ALARM_UNSET)
    {
        ds3231_get_time(dev, timeinfo);
        if ((old_timeinfo.tm_min != timeinfo->tm_min) || (old_timeinfo.tm_hour != timeinfo->tm_hour))
        {
            set_time(timeinfo->tm_hour, timeinfo->tm_min);
            memcpy(&old_timeinfo, timeinfo, sizeof(struct tm));
        }
        vTaskDelay(450 / portTICK_PERIOD_MS);
    }

    gpio_intr_disable(BUTTON_Y_PIN);
    execute_command(DFP_PAUSE, 0);
    vTaskDelay(100 / portTICK_PERIOD_MS);
    execute_command(DFP_PLAY, DFP_PLAY_SLEEP);
    if (ALARM_UNSET) // user woke up
    {
        gpio_intr_disable(BUTTON_N_PIN);
        memset(alarm, 0, sizeof(struct Alarm));
        ESP_LOGI("ALARM", "User woke up!");
    }
    else // user requested to sleep for some more time
    {
        alarm->time.tm_min = timeinfo->tm_min + 10;
        ESP_LOGI("ALARM", "User asked for 10 mins.");
        ESP_LOGI("ALARM", "Next alarm: %d:%d", alarm->time.tm_hour, alarm->time.tm_min);
    }

    ALARM_SET = false;
    ALARM_UNSET = false;
    gpio_intr_enable(SWITCH_PIN);
}

void app_main(void)
{
    init_gpio();
    if (uart_init() != ESP_OK)
        ESP_LOGE("UART", "Error in UART init, Can't use MP3 module.");
    init_DFPlayer();

    /* Print chip information */
    esp_chip_info_t chip_info;
    esp_chip_info(&chip_info);
    printf("This is %s chip with %d CPU core(s), WiFi%s%s, ",
            CONFIG_IDF_TARGET,
            chip_info.cores,
            (chip_info.features & CHIP_FEATURE_BT) ? "/BT" : "",
            (chip_info.features & CHIP_FEATURE_BLE) ? "/BLE" : "");

    printf("silicon revision %d, ", chip_info.revision);

    printf("%dMB %s flash\n", spi_flash_get_chip_size() / (1024 * 1024),
            (chip_info.features & CHIP_FEATURE_EMB_FLASH) ? "embedded" : "external");

    printf("Minimum free heap size: %d bytes\n", esp_get_minimum_free_heap_size());

    esp_err_t err = nvs_flash_init();
    if (err == ESP_ERR_NVS_NO_FREE_PAGES || err == ESP_ERR_NVS_NEW_VERSION_FOUND) {
      ESP_ERROR_CHECK(nvs_flash_erase());
      err = nvs_flash_init();
    }
    ESP_ERROR_CHECK(err);
    struct tm timeinfo = { 0 };
    bool synchronized = obtain_time(&timeinfo);

    i2c_dev_t dev = {
        .port = I2C_NUM_0,
        .addr = DS3231_ADDR,
        .sda_io_num = I2C_SDA_PIN,
        .scl_io_num = I2C_SCL_PIN,
        .clk_speed = I2C_FREQ_HZ,
    };
    init_RTC(&dev, &timeinfo, synchronized);
    // test_DFPlayer();
    // init_DFPlayer();

    struct tm old_timeinfo = { 0 };
    struct Alarm alarm_timeinfo = { 0 };

    power_nixie(true);

    // report_switch_states();
    // report_flags();
    handle = xQueueCreate(10, sizeof(struct encoder_data));

    while (true)
    {
        if (alarm_timeinfo.set)
        {
            if ((alarm_timeinfo.time.tm_min == timeinfo.tm_min) &&
                        (alarm_timeinfo.time.tm_hour == timeinfo.tm_hour))
            {
                execute_command(DFP_PLAY, DFP_PLAY_TF);
                vTaskDelay(300 / portTICK_PERIOD_MS);
                ESP_LOGI("ALARM", "ALARM triggered!");
                annoying_alarm_mode(&alarm_timeinfo, &timeinfo, &dev);
            }
        }
        if (ALARM_UNSET)
        {
            gpio_intr_disable(BUTTON_N_PIN);
            memset(&alarm_timeinfo, 0, sizeof(struct Alarm));
            ALARM_UNSET = false;
            ESP_LOGI("ALARM", "set ALARM_UNSET");
        }
        if (ALARM_MODE_SET)
        {
            ESP_LOGI("ALARM", "entering alarm mode");
            run_alarm_mode(&alarm_timeinfo, &handle);
            ds3231_get_time(&dev, &timeinfo);
            set_time(timeinfo.tm_hour, timeinfo.tm_min);
        }
        else
        {
            if (ds3231_get_time(&dev, &timeinfo) != ESP_OK) {
                ESP_LOGE(I2C, "Couldn't ask the current time.\n");
                break;
            }
            if ((old_timeinfo.tm_min != timeinfo.tm_min) || (old_timeinfo.tm_hour != timeinfo.tm_hour))
            {
                set_hour((int)(timeinfo.tm_hour / 10), (int)(timeinfo.tm_hour % 10));
                set_minutes((int)(timeinfo.tm_min / 10), (int)(timeinfo.tm_min % 10));
                memcpy(&old_timeinfo, &timeinfo, sizeof(struct tm));
                vTaskDelay(450 / portTICK_PERIOD_MS);
            }
            else
                vTaskDelay(300 / portTICK_PERIOD_MS);
        }
        vTaskDelay(300 / portTICK_PERIOD_MS);
    }
    power_nixie(false);

    
    for (int i = 10; i >= 0; i--) {
        printf("Restarting in %d seconds...\n", i);
        vTaskDelay(1000 / portTICK_PERIOD_MS);
    }
    printf("Restarting now.\n");
    fflush(stdout);
    esp_restart();
}

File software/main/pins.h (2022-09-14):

#ifndef PINS_H
#define PINS_H

#include "driver/gpio.h"

#define SHDN_PIN GPIO_NUM_32
#define BUTTON_Y_PIN GPIO_NUM_36 // SENSOR_VP
#define BUTTON_N_PIN GPIO_NUM_39 //SENSOR_VN
#define ENC_DATA_PIN GPIO_NUM_34
#define ENC_CLK_PIN GPIO_NUM_23
#define SWITCH_PIN GPIO_NUM_35
#define N1A_PIN GPIO_NUM_33
#define N1B_PIN GPIO_NUM_26
#define N1C_PIN GPIO_NUM_27
#define N1D_PIN GPIO_NUM_25
#define N2A_PIN GPIO_NUM_4
#define N2B_PIN GPIO_NUM_19
#define N2C_PIN GPIO_NUM_21
#define N2D_PIN GPIO_NUM_5
#define SHIFT_CLK_PIN GPIO_NUM_18
#define SHIFT_DSA_PIN GPIO_NUM_22
#define PLAYING_PIN GPIO_NUM_15
#define I2C_SDA_PIN GPIO_NUM_13
#define I2C_SCL_PIN GPIO_NUM_14
#define UART_TX_PIN GPIO_NUM_17
#define UART_RX_PIN GPIO_NUM_16

#endif

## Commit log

2022-07-14 First PCB ready.
    [KLS7-TS6601-13.0-180.step, Retro_clock.kicad_pcb, Retro_clock.kicad_sch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]
2022-07-22 Finished first pcb, 2nd schematics and footprints.
    [BH-18650-PC.step, Back_PCB.kicad_sch, DFR0299.step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]
2022-07-24 Final version without panelization.
    [Back_PCB.kicad_sch, Retro_clock.kicad_pcb, Retro_clock.kicad_sch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]
2022-07-25 Fixed some minor things, added panelization.
    [Retro_clock.kicad_pcb]
2022-09-05 Added code for shift register, i2c check.
2022-09-14 Added code for RTC, encoder, small logic for alarm.
2022-10-23 Changed locale, added code for DFPlayer. Notice: MH2024K responds correctly only after SD card is inserted.
    [dfplayer.c, main.c]
2022-10-29 Added debug funcs, fixed first number range, added player sleep mode.
    [main.c, test_hardware.c]
